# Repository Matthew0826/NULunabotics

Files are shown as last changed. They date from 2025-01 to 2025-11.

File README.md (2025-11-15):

Welcome to the NU Lunabotics Repository! This is the place for all IP for NU Lunabotics.

For Github to commit changes correctly ensure you run:
$ git config --global core.fileMode false

To run the repository in a docker container:
1. Open the project from the ROS folder (important so it can recognize our Dockerfile)
2. Ctrl + Shift + P
3. Open and Rebuild Container
4. $ ./launch_theia.sh to run the website + theia

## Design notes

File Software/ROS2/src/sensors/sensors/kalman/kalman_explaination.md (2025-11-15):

# Robot Location Tracking System

This code implements a location tracking system that uses distance measurements from fixed beacons and optional accelerometer data to figure out where a robot is. Let's break it down:

## What This Code Does

The system tracks a robot's position (x,y coordinates) by:
1. Taking distance measurements from three fixed beacons
2. Optionally using accelerometer data to improve accuracy
3. Applying statistical filtering to handle measurement errors
4. Estimating the most likely position based on all available data

## Core Components

### Main Classes

#### ExtendedKalmanFilter
This is the statistical heart of the system. It maintains an estimated state (position and velocity) and continuously refines it based on measurements.

```
Class ExtendedKalmanFilter:
    Initialize with:
        - Motion model (how we expect position to change over time)
        - Error models (how much we trust our predictions vs measurements)
        - Initial guess of position and velocity
        - Locations of fixed beacons
    
    Method predict():
        # Predict where robot should be now based on previous state
        Apply motion model to update state estimate
        Increase uncertainty to account for prediction errors
    
    Method update(distance_measurements, accel_measurements):
        # Validate incoming measurements first
        distances, accels = validate_measurements(...)
        
        # Calculate what measurements we'd expect to see if our current estimate is correct
        expected_distances = calculate_distances_from_current_estimate_to_beacons()
        
        # Compare actual to expected measurements (the difference is called "innovation")
        innovation = actual_measurements - expected_measurements
        
        # Calculate how much to trust these measurements
        adaptive_trust_factor = calculate_trust_based_on_measurement_quality()
        
        # Compute an optimal adjustment factor (balancing our prediction vs measurements)
        adjustment_factor = calculate_optimal_adjustment()
        
        # Update our position estimate using this balanced approach
        state = state + adjustment_factor * innovation
        
        # Update uncertainty estimates
        update_uncertainty_estimates()
        
        return innovation
        
    Method check_filter_health():
        # See if filter is working well or needs reset
        if position_uncertainty > THRESHOLD and consistent_large_errors:
            reset_uncertainty_to_reasonable_values()
            return True
        return False
```

### Helper Functions

```
Function validate_measurements(distance_measurements, accel_measurements):
    # Remove obviously wrong measurements
    Filter out distances < MIN_VALID_DISTANCE or > MAX_VALID_DISTANCE
    
    if accel_measurements provided:
        Filter out accelerations > MAX_VALID_ACCEL
        
    return cleaned_distances, cleaned_accels

Function adaptive_measurement_covariance(distances, accels):
    # Calculate how much to trust each measurement
    # Larger distances or accelerations get less trust
    
    for each distance:
        trust_factor = adjust_based_on_distance_magnitude()
    
    for each acceleration:
        trust_factor = adjust_based_on_acceleration_magnitude()
        
    return trust_factors
```

### Main Function

```
Function find_robot_location(distance_to_A, distance_to_B, distance_to_C, accel_x, accel_y):
    # Smooth accelerometer data with low-pass filter
    smoothed_accel = apply_low_pass_filter(accel_x, accel_y)
    
    # Update how much uncertainty to add in prediction step
    adjust_prediction_uncertainty(smoothed_accel)
    
    # Predict new position based on motion model
    ekf.predict()
    
    # Update estimate with new measurements
    innovation = ekf.update(distances, smoothed_accel)
    
    # Store history for diagnostics
    save_to_history(innovation, current_position, current_uncertainty)
    
    # Check if filter needs reset due to poor performance
    ekf.check_filter_health()
```

## How It Works (The Math Simplified)

1. **State Representation**: The system tracks four values in a vector: [x, vx, y, vy] where x,y are position and vx,vy are velocity

2. **Prediction Step**: At each time step (dt), the system predicts:
   ```
   new_x = x + vx*dt
   new_vx = vx
   new_y = y + vy*dt
   new_vy = vy
   ```

3. **Measurement Model**: It compares actual measurements with expected measurements:
   - Expected distance to each beacon = sqrt((x-beacon_x)² + (y-beacon_y)²)
   - Expected acceleration = 0 (assuming constant velocity)

4. **Update Step**: The system calculates:
   - Difference between actual and expected measurements
   - How much to trust each difference (based on distance size, acceleration size)
   - Optimal way to adjust current estimate based on new measurements
   - Updates position and velocity estimates accordingly

5. **Health Checks**: If uncertainty gets too high or measurements consistently disagree with predictions, the system resets its uncertainty estimates.

## Flow Summary

1. Initialize with a guess of robot position and reasonable uncertainty
2. For each new set of measurements:
   - Predict where robot should be now based on previous position and velocity
   - Compare beacon distances with expected distances
   - Calculate optimal adjustment to estimated position
   - Update position estimate and uncertainty values
   - Check if filter is working properly
   - Return best estimate of current position

This approach optimally balances the uncertainty in the motion model against the uncertainty in the sensor measurements, giving more weight to whichever is more reliable at any given moment.

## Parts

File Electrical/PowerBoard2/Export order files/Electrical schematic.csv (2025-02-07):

Reference | Value | Datasheet | Footprint | Qty | DNP
C1,C2 | 20SVPF120M | 20SVPF120M | PCAP_SVP_C6_PAN | 2
C3 | 25SVPF47M | 25SVPF47M | PCAP_SVP_C6_PAN | 1
C10 | 0.1uF | ~ | Capacitor_SMD:C_0805_2012Metric_Pad1.18x1.45mm_HandSolder | 1
C11 | 1nF | ~ | Capacitor_SMD:C_0805_2012Metric_Pad1.18x1.45mm_HandSolder | 1
J1 | S4B-XH-SM4-TB | S4B-XH-SM4-TB | CONN4_S4B-XH_JST | 1
J2,J3,J5 | XT60PW-M |  | Connector_AMASS:AMASS_XT60IPW-M_1x03_P7.20mm_Horizontal | 3
J4 | 2171750001 | 2171750001 | 2171750001_MOL | 1
R1 | ERJ-6ENF1071V | ERJ-6ENF1071V | RC0805N_PAN | 1
R2 | ERJ-6ENF5621V | ERJ-6ENF5621V | RC0805N_PAN | 1
R3,R4 | 5.1k | ~ | Resistor_SMD:R_0805_2012Metric_Pad1.20x1.40mm_HandSolder | 2
R5 | 1M | ~ | Resistor_SMD:R_0805_2012Metric_Pad1.20x1.40mm_HandSolder | 1
R6 | 0.333M | ~ | Resistor_SMD:R_0805_2012Metric_Pad1.20x1.40mm_HandSolder | 1
U1 | LMZ22005TZ/NOPB | LMZ22005TZ/NOPB | TZA07A | 1
U2 | ACS715LLCTR-30A-T | ACS715LLCTR-30A-T | SOIC-8_ALM | 1
U3 | TLV2370IDBVR |  | TLV2370IDBVR:SOT95P280X145-6N | 1
U4 | TMUX1204DGSR | TMUX1204DGSR | DGS0010A-IPC_A | 1

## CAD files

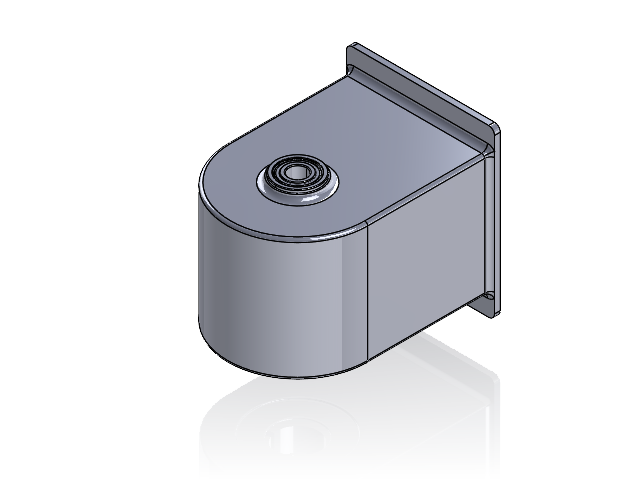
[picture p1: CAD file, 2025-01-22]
2XX-XXXX (Mechanical)/21X-XXXX (Mobility)/211-XXXX (Drivetrain)/211-00XX (Swerve System)/211-009X (Sub-Assemblies)/211-0092 (Differential Gearbox Assembly).SLDASM
211-0021 (Gearbox Casing)
211-0022 (28 Tooth Bevel Gear).step x 2
1301-0016-0014.STEP
2800-0004-0010_90128A207.STEP
1311-0016-1006.STEP
2800-0004-0014_90128A207.STEP x 2
211-0001 (6mm ID Flanged Bearing).step x 2
211-0025 (Central Spacer)

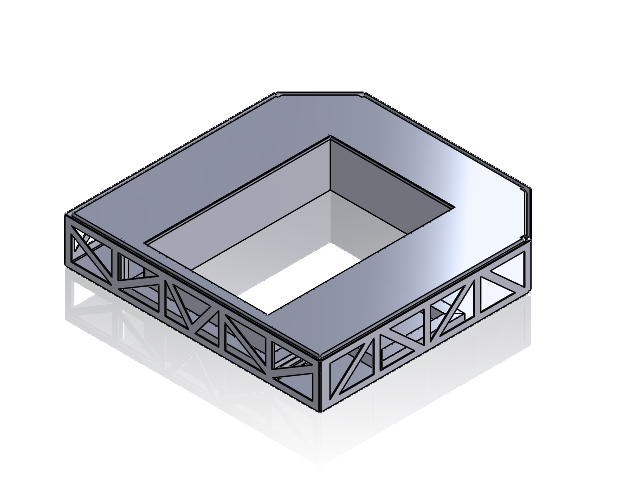
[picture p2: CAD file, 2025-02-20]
Mechanical/Chassis/Sheet Metal Chassis/Chassis2_Assy.SLDASM
Chassis_Bottom-Shell
Chassis Frame
Chassis_Rib
Chassis_Rib2
296x110_Panel x 2
450x110_Panel x 2
Chassis_Top-Shell

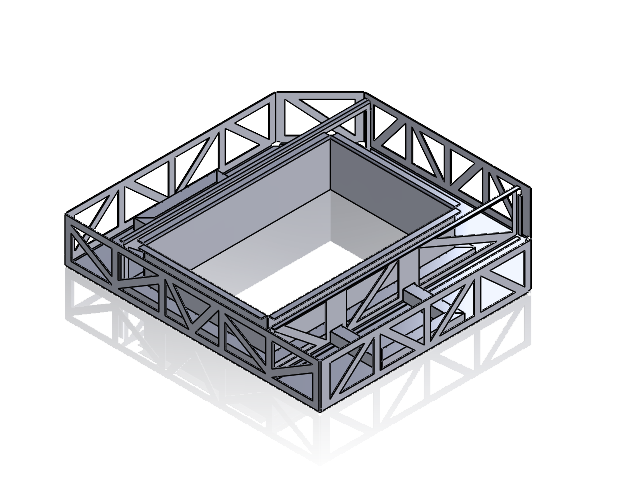
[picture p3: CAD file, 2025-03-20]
Mechanical/Lunabotics2025_Chassis_Design/CAD_Lunbotics 2025/Chassis2_Assy.SLDASM
Chassis_Bottom-Shell
Chassis Frame
Chassis_Rib
Chassis_Rib2
296x110_Panel x 2
450x110_Panel x 2

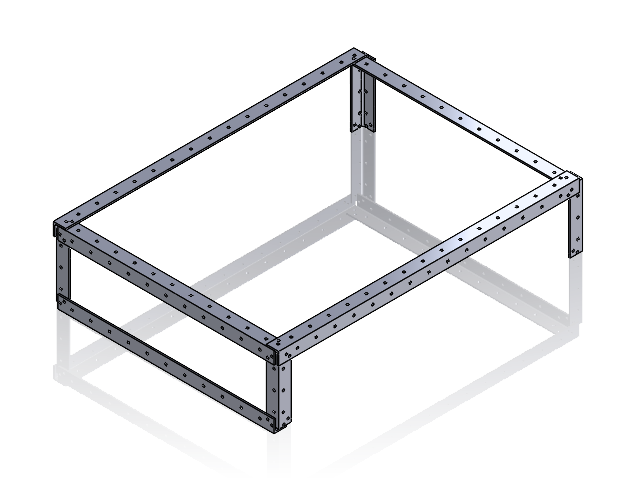
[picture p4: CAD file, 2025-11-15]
Mechanical/Lunabotics2025_Chassis_Design/Chassis_3/L-Bar Frame.SLDASM
L-Bar_1x1_8th_inch_558.8mm x 3
L-Bar_1x1_8th_inch x 2
L-Bar_1x1_8th_4inch x 4

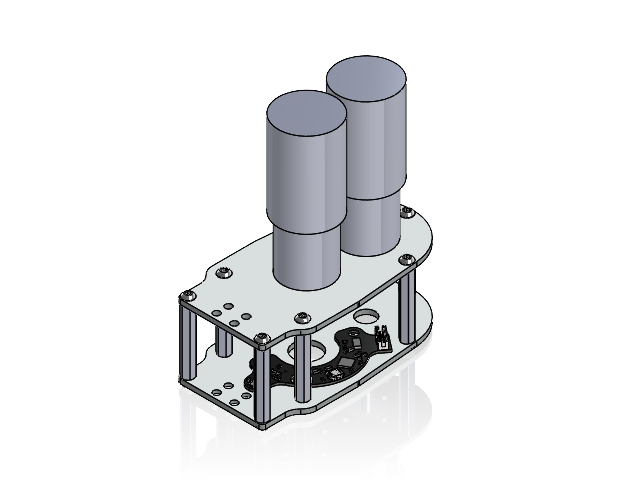
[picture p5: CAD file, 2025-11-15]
Mechanical/Experimental/Swerve Modules/Chassis Structure/Fixed Components/Gearbox Casing/Gearbox Casing Assembly.SLDASM
Top Interface Panel
Motor Mounting Plate
Lamprey
Motor x 2
43mm Hex Standoff.step x 7
M4 Button Head 12mm x 14

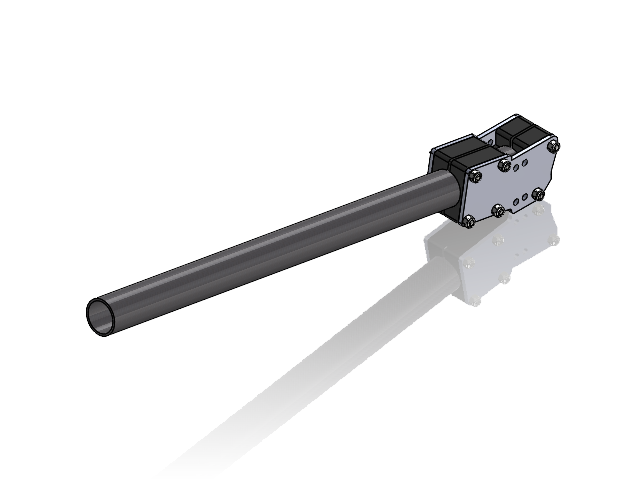
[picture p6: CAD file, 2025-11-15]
Mechanical/Experimental/Swerve Modules/Chassis Structure/Fixed Components/Tube Mount/Tube Mount Assembly.SLDASM
Tube
Tube Clamp Left
Tube Clamp Right
Tube Clamp Plate x 2
M4 40mm x 6
M4 Lock Nut x 6

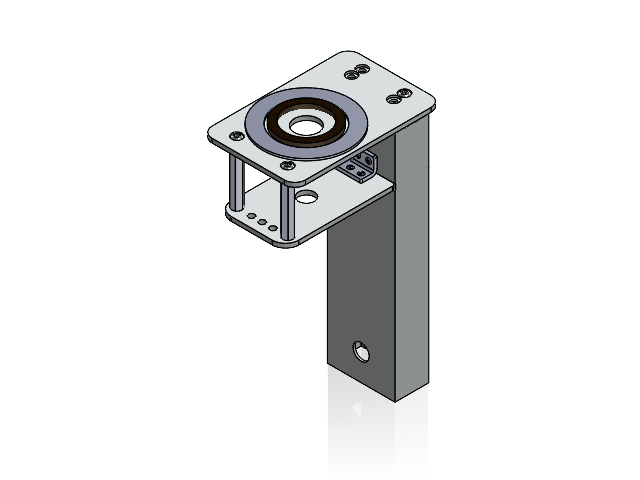
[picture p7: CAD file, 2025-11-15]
Mechanical/Experimental/Swerve Modules/Wheel Structure/Fixed Components/Differential Gearbox Case.SLDASM
Bottom Interface Plate
43mm Hex Standoff.step x 2
M4 Button Head 12mm x 2
Modified GoBilda L-Bracket x 2
Wheel Tube
Wheel Cover Plate
Lamprey Magnet Ring.step
GoBilda L-Bracket.step x 2
Part9^Thrust Bearing
5mm M4 Bolt

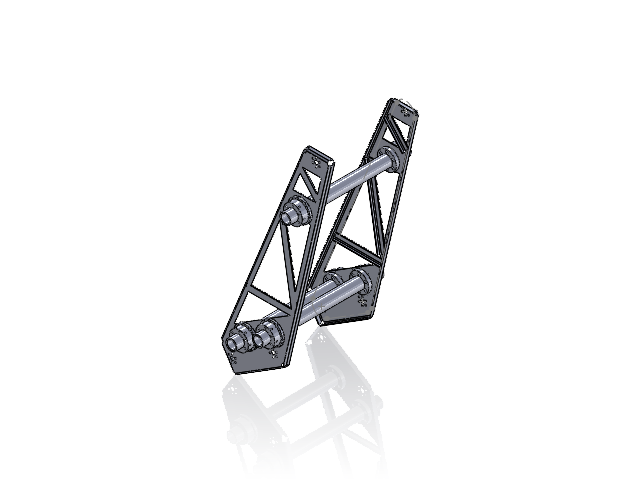
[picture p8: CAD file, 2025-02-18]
Mechanical/Lunabotics2025_Chassis_Design/Conveyer/Conveyer_Assy.SLDASM
Rib_1 x 2
Rib_2 x 2
Rib_3 x 2
Side_Frame
Side_Frame_2
300MM_PVC x 3
PVC_Attachment1 x 6
PVC_Attachment2 x 6

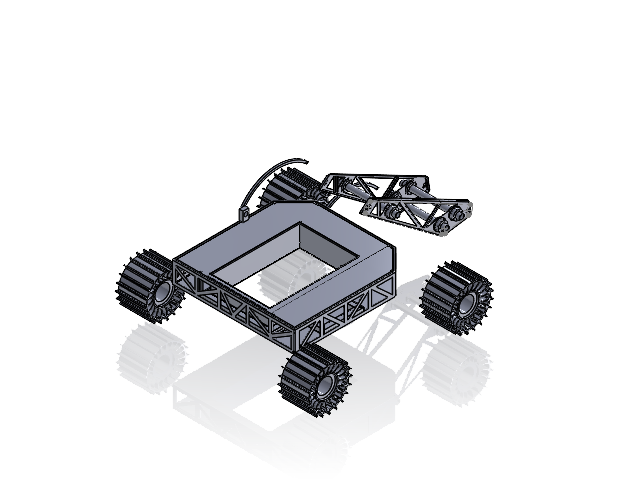
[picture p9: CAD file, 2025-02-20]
Mechanical/Chassis/Maharshi Blocking/Luna_Assy.SLDASM
Chassis_Bottom-Shell
Chassis Frame
Chassis_Rib
Chassis_Rib2
296x110_Panel x 2
450x110_Panel x 2
Chassis_Top-Shell
Rib_1 x 2
Rib_2 x 2
Rib_3 x 2
Side_Frame
Side_Frame_2
300MM_PVC x 3
PVC_Attachment1 x 6
PVC_Attachment2 x 6
Dummy_Wheel_226mm x 4
Dummy_Hinge x 2
Dummy_Arm-1
Dummy_Arm-2

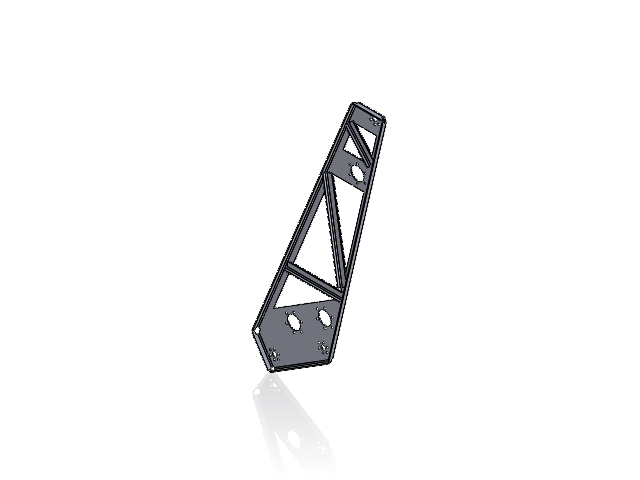
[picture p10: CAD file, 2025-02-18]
Mechanical/Lunabotics2025_Chassis_Design/Conveyer/Side_Frame_1_assy.SLDASM
Rib_1
Rib_2
Rib_3
Side_Frame

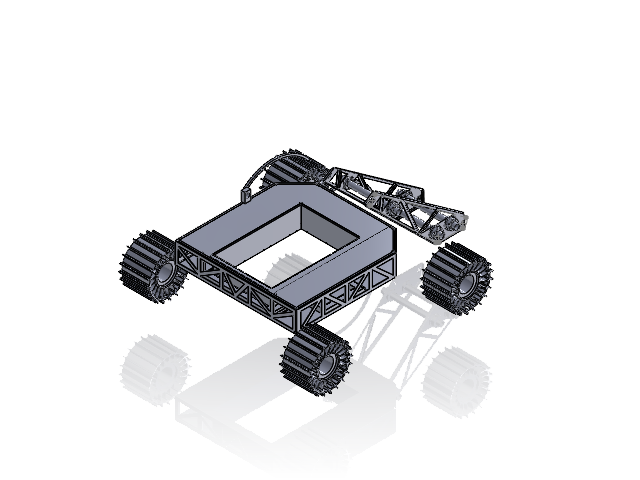
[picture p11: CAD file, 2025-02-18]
Mechanical/Lunabotics2025_Chassis_Design/Luna_Assy.SLDASM
Chassis_Bottom-Shell
Chassis Frame
Chassis_Rib
Chassis_Rib2
296x110_Panel x 2
450x110_Panel x 2
Chassis_Top-Shell
Rib_1 x 2
Rib_2 x 2
Rib_3 x 2
Side_Frame
Side_Frame_2
300MM_PVC x 3
PVC_Attachment1 x 6
PVC_Attachment2 x 6
Dummy_Wheel_226mm x 4
Dummy_Hinge x 2
Dummy_Arm-1
Dummy_Arm-2

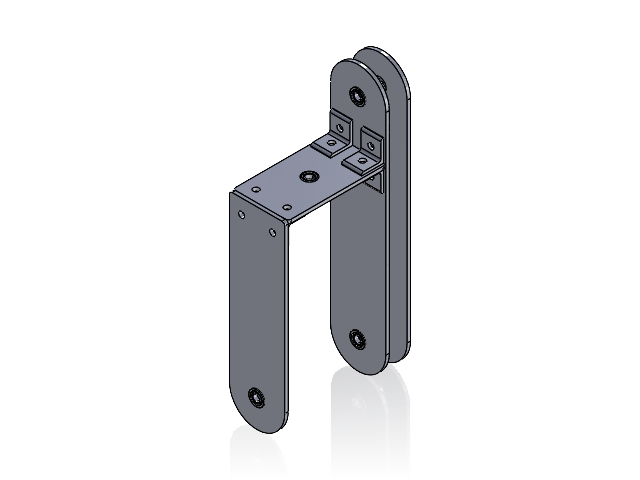
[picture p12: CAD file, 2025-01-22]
Mechanical/Experimental/Swerve Modules/Wheel Mount Assembly.SLDASM
211-0002 (Master Sketch v2)
211-0010 (Belt Protection Panel)
211-0016 (Outer Belt Protection Panel)
211-0018 (Wheel Top Plate)
211-0015 (Corner Bracket) x 6
211-0017 (Wheel Support Plate)
211-0012 (6mm ID 12mm OD Flanged Bearing).step x 6

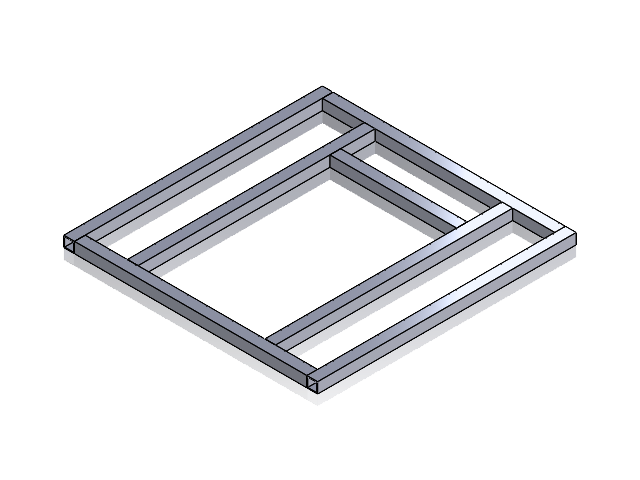
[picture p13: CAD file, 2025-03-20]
Mechanical/Lunabotics2025_Chassis_Design/Chassis_2/Chassis_2_Frame_Assy.SLDASM
1x1inch_612mmBeam x 2
1x1inch_550mmBeam x 2
1x1inch_561.2mmBeam x 2
1x1inch_300mmBeam

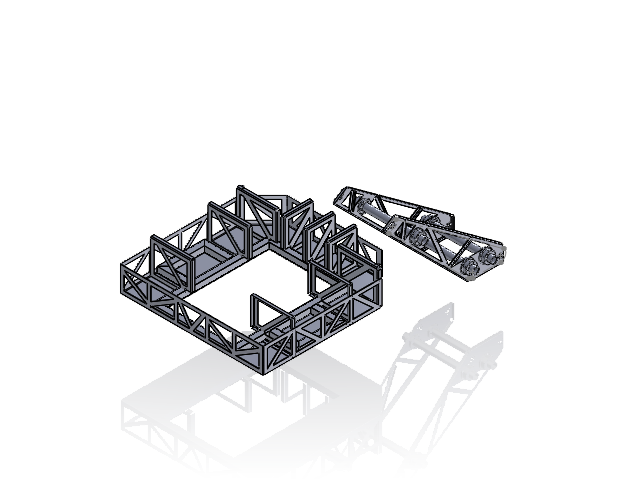
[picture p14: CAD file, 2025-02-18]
Mechanical/Lunabotics2025_Chassis_Design/CAD_Lunbotics 2025/Chassis_Assy.SLDASM
Chassis_Bottom-Shell
Chassis Frame
Front_L-Bracket x 3
Front_Left-Corner_L-Bracket
Front_Right-Corner_L-Bracket
Side_L-Bracket x 4
Rib_1 x 2
Rib_2 x 2
Rib_3 x 2
Side_Frame
Side_Frame_2
300MM_PVC x 3
PVC_Attachment1 x 6
PVC_Attachment2 x 6

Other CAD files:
Mechanical/Excavation/Conveyer/Conveyer_Assy.SLDASM
Mechanical/Experimental/Swerve Modules/Wheel Structure/Fixed Components/Thrust Bearing.SLDASM
Mechanical/Lunabotics2025_Chassis_Design/Chassis_2/Chassis_2_Assy.SLDASM
Electrical/SparkMiniMount.SLDPRT
Mechanical/4BarGBInnerLg.STL
Mechanical/4BarGBInnerLgr.STL
Mechanical/4BarGBOuter.STL
Mechanical/4BarGearboxLg.STL
Mechanical/4BarGearboxSmall.SLDPRT
Mechanical/4BarGearboxSmall.STL
Mechanical/;;.dxf
Mechanical/Big Boi Cut.DWG
Mechanical/Big Boi Cut_imported_DWG.dxf
Mechanical/Blocking.SLDPRT
Mechanical/Blockingv2.DWG
Mechanical/Blockingv2.SLDPRT
Mechanical/Chassis/Chassis v2/Chassis_2_Assy.SLDASM
Mechanical/Chassis/Chassis v3/12x6inch_side_frame.SLDPRT
Mechanical/Chassis/Chassis v3/Bottom_Plate.SLDPRT
Mechanical/Chassis/Chassis v3/Chassis_3_assy.SLDASM
Mechanical/Chassis/Chassis v3/L-Bar_1x1_8th_4inch.SLDPRT
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

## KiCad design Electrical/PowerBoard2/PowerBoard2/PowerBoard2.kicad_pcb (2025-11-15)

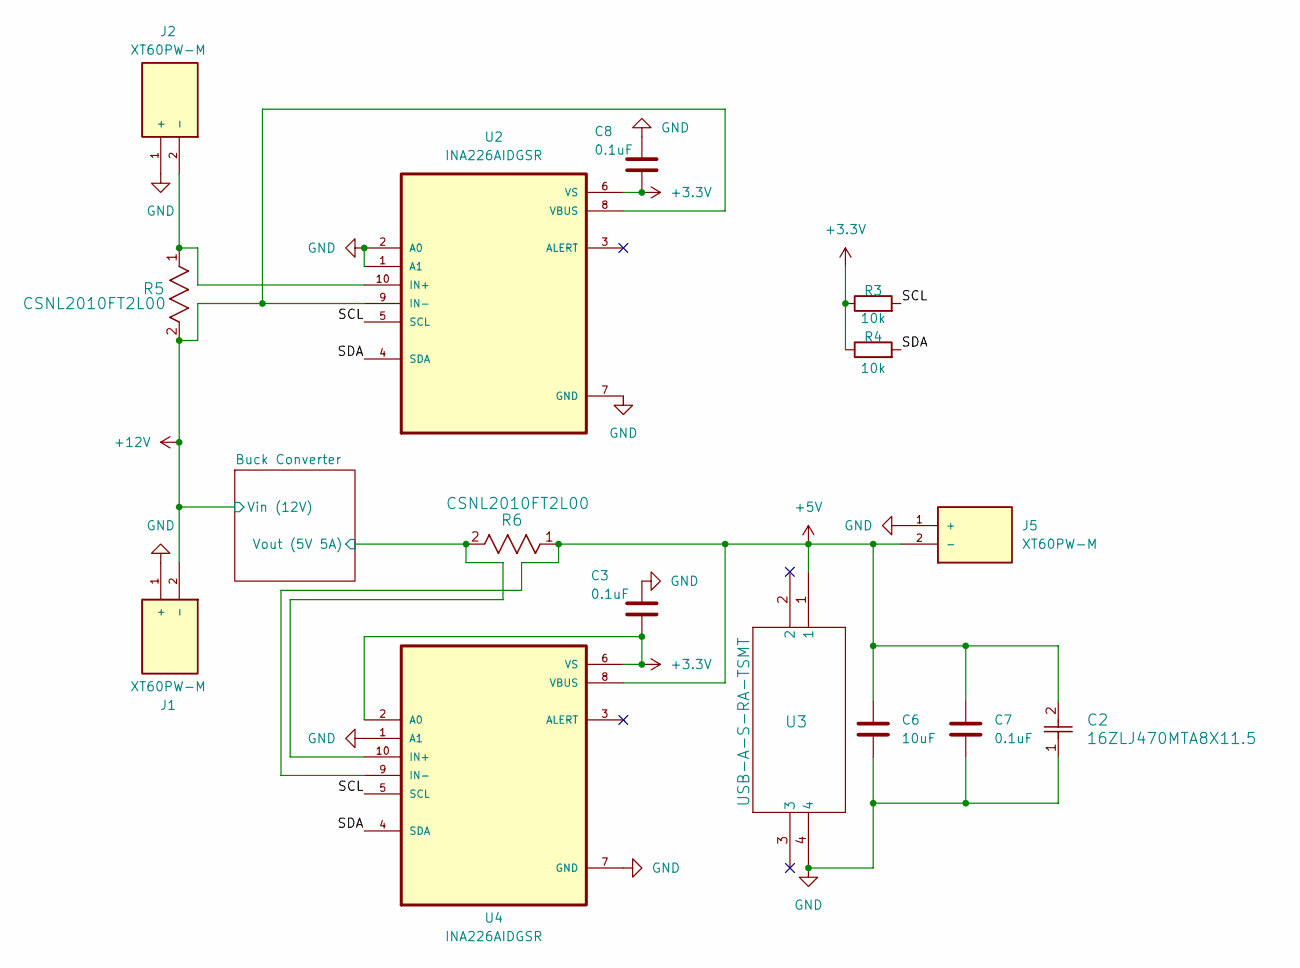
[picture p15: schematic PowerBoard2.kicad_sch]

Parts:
C2: 16ZLJ470MTA8X11.5; CAP_YX_8X11P5_RUB
C3, C7, C8: 0.1uF; C_0805_2012Metric_Pad1.18x1.45mm_HandSolder
C6: 10uF; C_0805_2012Metric_Pad1.18x1.45mm_HandSolder
J1, J2, J5: XT60PW-M; AMASS_XT60IPW-M_1x03_P7.20mm_Horizontal; PARTREV V1.2
R3, R4: 10k; R_0805_2012Metric_Pad1.20x1.40mm_HandSolder
R5, R6: CSNL2010FT2L00; STA_CSNL2010&lessthan_=3_STP
U2, U4: INA226AIDGSR
U3: USB-A-S-RA-TSMT; USB-A-S-RA-TSMT_ADM

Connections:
+3.3V: C3.1, C8.1, R3.1, R4.1, U2.6 (VS), U4.2 (A0), U4.6 (VS); also elsewhere on the board
+5V: C2.2, C6.1, C7.1, J5.2 (-), R6.1, U3.1, U4.8 (VBUS), U4.9 (IN-); also elsewhere on the board
+12V: J1.2 (-), R5.2, U2.8 (VBUS), U2.9 (IN-); also elsewhere on the board
/Buck Converter/Vout (5V 5A): R6.2, U4.10 (IN+); also elsewhere on the board
/SCL: R3.2, U2.5 (SCL), U4.5 (SCL); also elsewhere on the board
/SDA: R4.2, U2.4 (SDA), U4.4 (SDA); also elsewhere on the board
GND: C2.1, C3.2, C6.2, C7.2, C8.2, J1.1 (+), J2.1 (+), J5.1 (+), U2.1 (A1), U2.2 (A0), U2.7 (GND), U3.4, U4.1 (A1), U4.7 (GND); also elsewhere on the board
unnamed: J2.2 (-), R5.1, U2.10 (IN+)

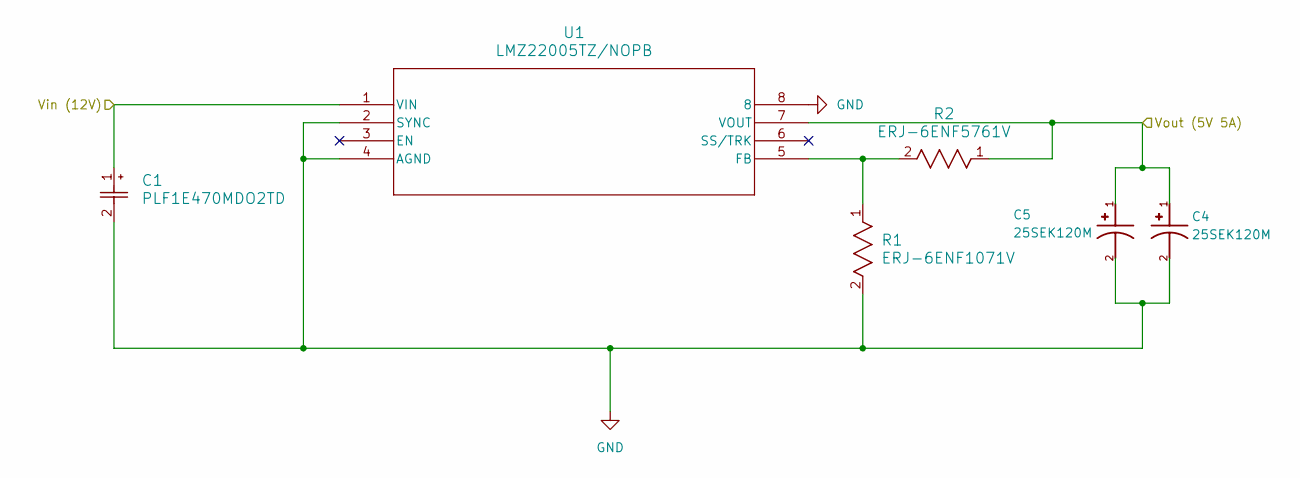
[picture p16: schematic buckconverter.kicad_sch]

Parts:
C1: PLF1E470MDO2TD
C4, C5: 25SEK120M; PARTREV 30-Oct-17
R1: ERJ-6ENF1071V; RC0805N_PAN
R2: ERJ-6ENF5761V; RC0805N_PAN
U1: LMZ22005TZ/NOPB; TZA07A

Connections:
+12V: C1.1, U1.1 (VIN); also elsewhere on the board
/Buck Converter/Vout (5V 5A): C4.1, C5.1, R2.1, U1.7 (VOUT); also elsewhere on the board
GND: C1.2, C4.2, C5.2, R1.2, U1.2 (SYNC), U1.4 (AGND), U1.8; also elsewhere on the board
unnamed: R1.1, R2.2, U1.5 (FB)

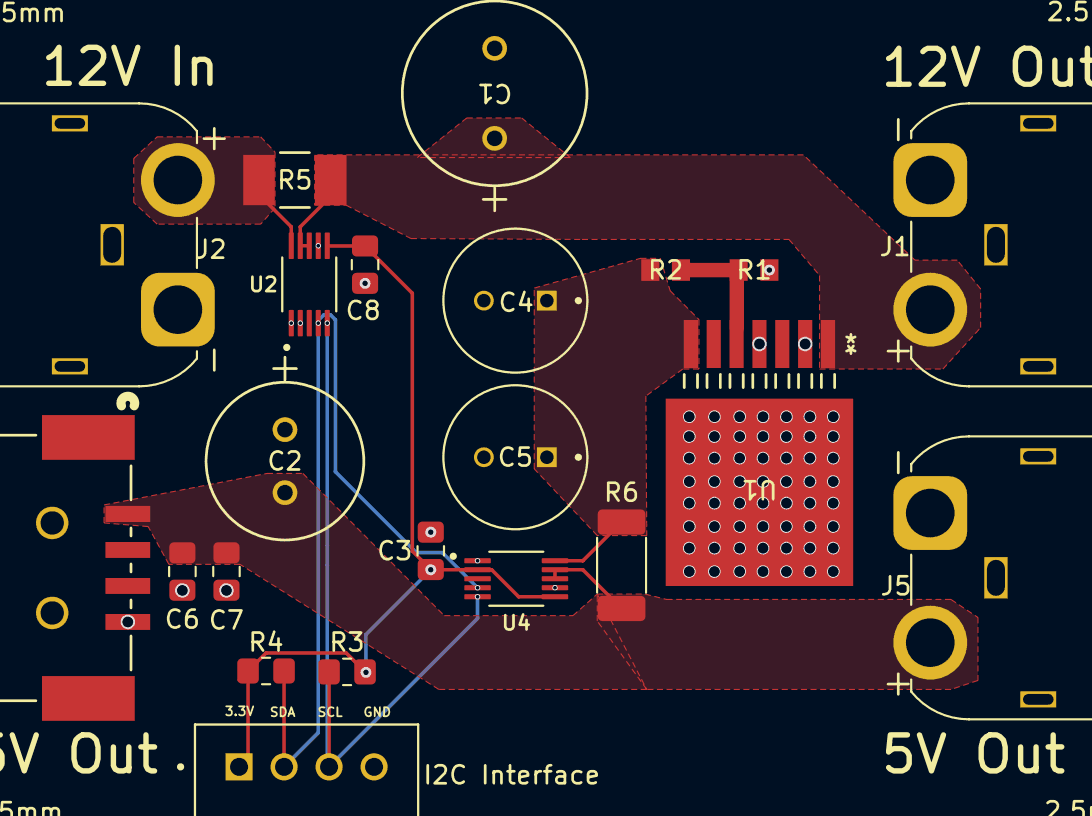
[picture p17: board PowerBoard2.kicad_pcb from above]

Board: 2 copper layers, 26 parts (0 on the bottom side), 9 nets.

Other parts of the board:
2.5mm, 2.5mm#2, 2.5mm#3, 2.5mm#4: MountingHole_2.5mm
5V Out: USB-A-S-RA-TSMT; USB-A-S-RA-TSMT_ADM
I2C Interface: B4B-XH-A_LF__SN_; JST_B4B-XH-A_LF__SN_

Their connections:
+3.3V: I2C Interface.1; also elsewhere on the board
+5V: 5V Out.1; also elsewhere on the board
/SCL: I2C Interface.3; also elsewhere on the board
/SDA: I2C Interface.2; also elsewhere on the board
GND: 5V Out.4, I2C Interface.4; also elsewhere on the board

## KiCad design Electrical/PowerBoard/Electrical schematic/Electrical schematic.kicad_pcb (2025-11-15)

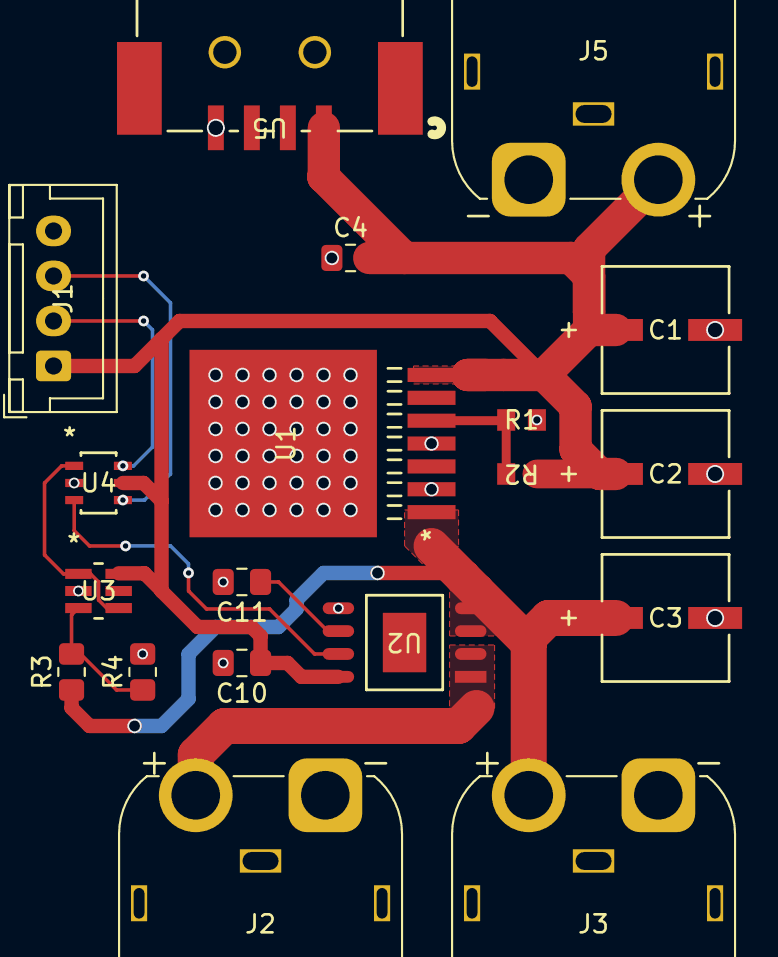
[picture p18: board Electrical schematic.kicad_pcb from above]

Board: 2 copper layers, 19 parts (0 on the bottom side), 11 nets.

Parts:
C1, C2: 20SVPF120M; PCAP_SVP_C6_PAN
C3: 25SVPF47M; PCAP_SVP_C6_PAN
C4: 330uF; C_0805_2012Metric_Pad1.18x1.45mm_HandSolder
C10: 0.1uF; C_0805_2012Metric_Pad1.18x1.45mm_HandSolder
C11: 1nF; C_0805_2012Metric_Pad1.18x1.45mm_HandSolder
J1: S4B-XH-SM4-TB; JST_XH_B4B-XH-A_1x04_P2.50mm_Vertical
J2, J3, J5: XT60PW-M; AMASS_XT60IPW-M_1x03_P7.20mm_Horizontal
R1: ERJ-6ENF1071V; RC0805N_PAN
R2: ERJ-6ENF5761V; RC0805N_PAN
R3: 1M; R_0805_2012Metric_Pad1.20x1.40mm_HandSolder
R4: 0.333M; R_0805_2012Metric_Pad1.20x1.40mm_HandSolder
U1: LMZ22005TZ/NOPB; TZA07A
U2: ACS715LLCTR-30A-T; SOIC-8_ALM
U3: TLV2370IDBVR; DBV6
U4: 74LVC1G157GV_125; TSOP6_SOT457_NEX
U5: USB-A-S-RA-TSMT; USB-A-S-RA-TSMT_ADM

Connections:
/Buck Converter/Vin (12V): C3.1, J3.2 (-), R3.1, U1.1 (VIN), U2.3 (IP-), U2.4 (IP-)
/Buck Converter/Vout (5V 5A): C1.1, C2.1, C4.2, C10.1, J1.1, J5.2 (-), R2.1, U1.7 (VOUT), U2.8 (VCC), U3.6 (VDD), U4.5 (VCC), U5.1
/Current Sensor/CURRENT IN: J2.2 (-), U2.1 (IP+), U2.2 (IP+)
/Current Sensor/VOLTAGE OUT (of reading): U2.7 (VIOUT), U4.3 (I0)
GND: C1.2, C2.2, C3.2, C4.1, C10.2, C11.2, J1.4, J2.1 (+), J3.1 (+), J5.1 (+), R1.2, R4.2, U1.2 (SYNC), U1.4 (AGND), U1.8, U2.5 (GND), U3.2 (GND), U4.2 (GND), U5.4
unnamed: R1.1, R2.2, U1.5 (FB)
unnamed: C11.1, U2.6 (FILTER)
unnamed: R3.2, R4.1, U3.3 (IN+)
unnamed: U3.1 (OUT), U3.4 (IN-), U4.1 (I1)
unnamed: J1.2, U4.6 (S)
unnamed: J1.3, U4.4 (Y)

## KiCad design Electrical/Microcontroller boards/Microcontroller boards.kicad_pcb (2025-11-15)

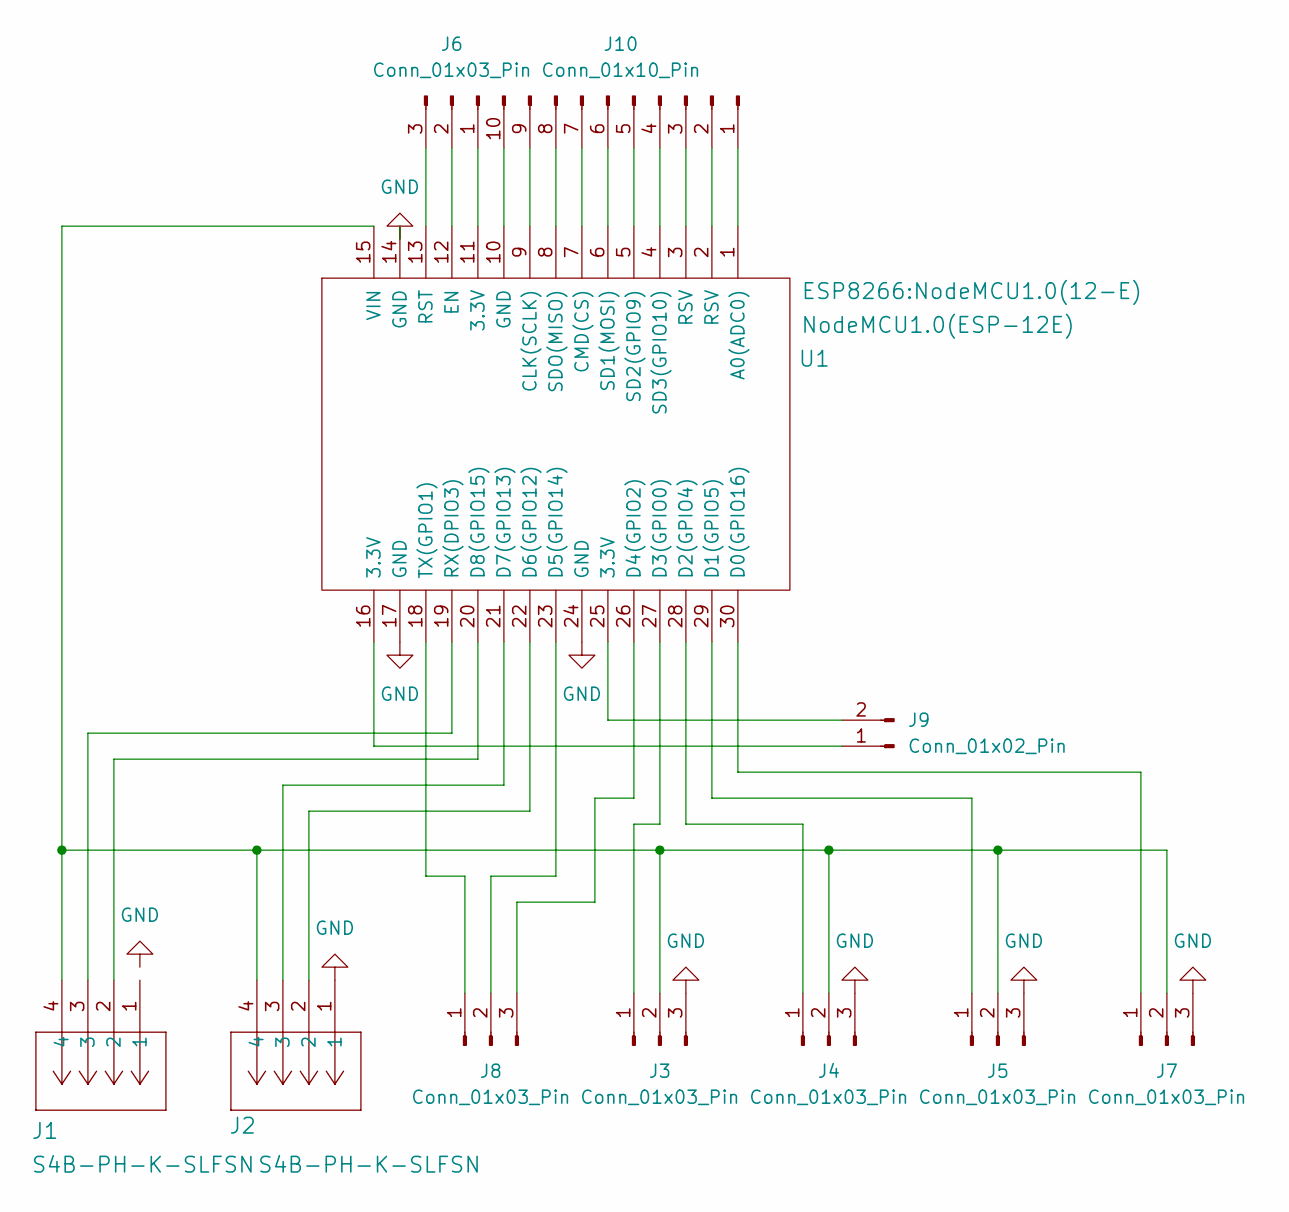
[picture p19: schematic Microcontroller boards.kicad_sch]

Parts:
J1, J2: S4B-PH-K-SLFSN; CONN_S4B-PH-K-S_JST
J3, J4, J5, J6, J7, J8: Conn_01x03_Pin; Wuerth_WR-WTB_64800311622_1x03_P1.50mm_Vertical
J9: Conn_01x02_Pin; Wuerth_WR-WTB_64800311622_1x02_P1.50mm_Vertical
J10: Conn_01x10_Pin; Wuerth_WR-WTB_64801011622_1x10_P1.50mm_Vertical
U1: NodeMCU1.0(ESP-12E); NodeMCU1.0(12-E)

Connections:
GND: J2.1, J3.3, J4.3, J5.3, J7.3, U1.14 (GND), U1.17 (GND), U1.24 (GND)
unnamed: J3.1, U1.27 (D3(GPIO0))
unnamed: J1.4, J2.4, J3.2, J4.2, J5.2, J7.2, U1.15 (VIN)
unnamed: J4.1, U1.28 (D2(GPIO4))
unnamed: J5.1, U1.29 (D1(GPIO5))
unnamed: J6.1, U1.11 (3.3V)
unnamed: J6.2, U1.12 (EN)
unnamed: J6.3, U1.13 (RST)
unnamed: J7.1, U1.30 (D0(GPIO16))
unnamed: J8.1, U1.18 (TX(GPIO1))
unnamed: J8.2, U1.23 (D5(GPIO14))
unnamed: J8.3, U1.26 (D4(GPIO2))
unnamed: J9.1, U1.16 (3.3V)
unnamed: J9.2, U1.25 (3.3V)
unnamed: J10.1, U1.1 (A0(ADC0))
unnamed: J10.2, U1.2 (RSV)
unnamed: J10.3, U1.3 (RSV)
unnamed: J10.4, U1.4 (SD3(GPIO10))
unnamed: J10.5, U1.5 (SD2(GPIO9))
unnamed: J10.6, U1.6 (SD1(MOSI))
unnamed: J10.7, U1.7 (CMD(CS))
unnamed: J10.8, U1.8 (SDO(MISO))
unnamed: J10.9, U1.9 (CLK(SCLK))
unnamed: J10.10, U1.10 (GND)
unnamed: J2.2, U1.22 (D6(GPIO12))
unnamed: J2.3, U1.21 (D7(GPIO13))
unnamed: J1.2, U1.20 (D8(GPIO15))
unnamed: J1.3, U1.19 (RX(DPIO3))

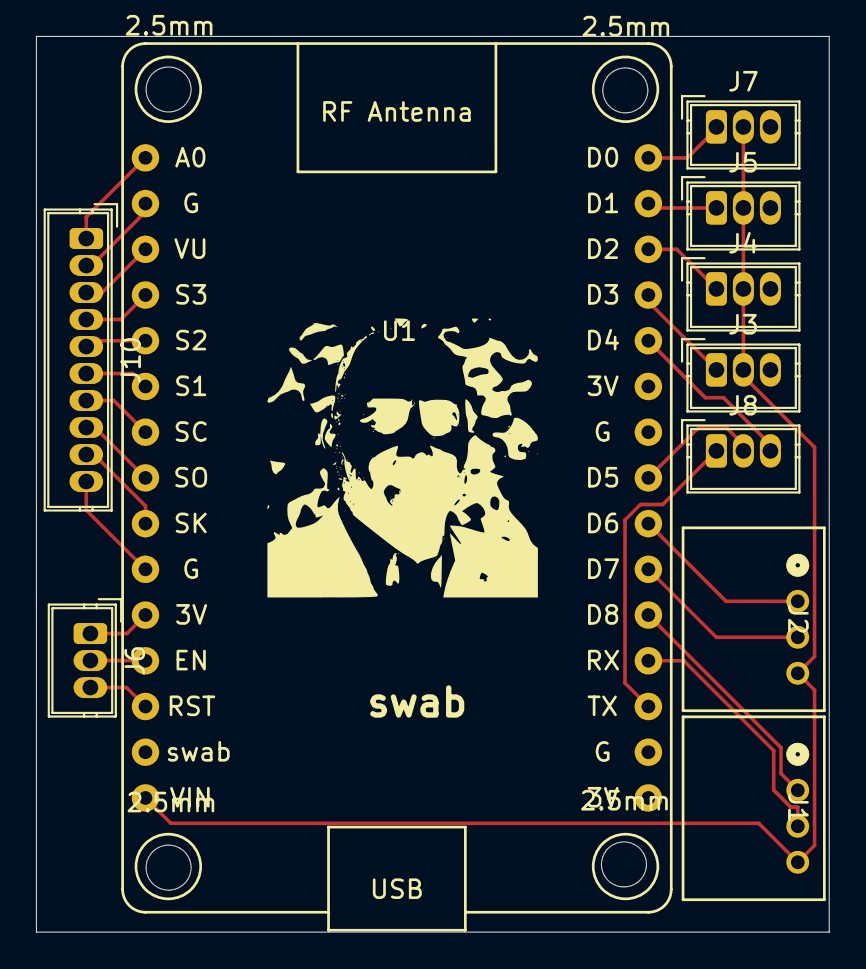
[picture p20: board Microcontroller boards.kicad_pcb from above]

Board: 2 copper layers, 44.0 x 49.8 mm, 15 parts (0 on the bottom side), 26 nets.

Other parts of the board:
2.5mm, 2.5mm#2, 2.5mm#3, 2.5mm#4: MountingHole_2.5mm
swab: LOGO

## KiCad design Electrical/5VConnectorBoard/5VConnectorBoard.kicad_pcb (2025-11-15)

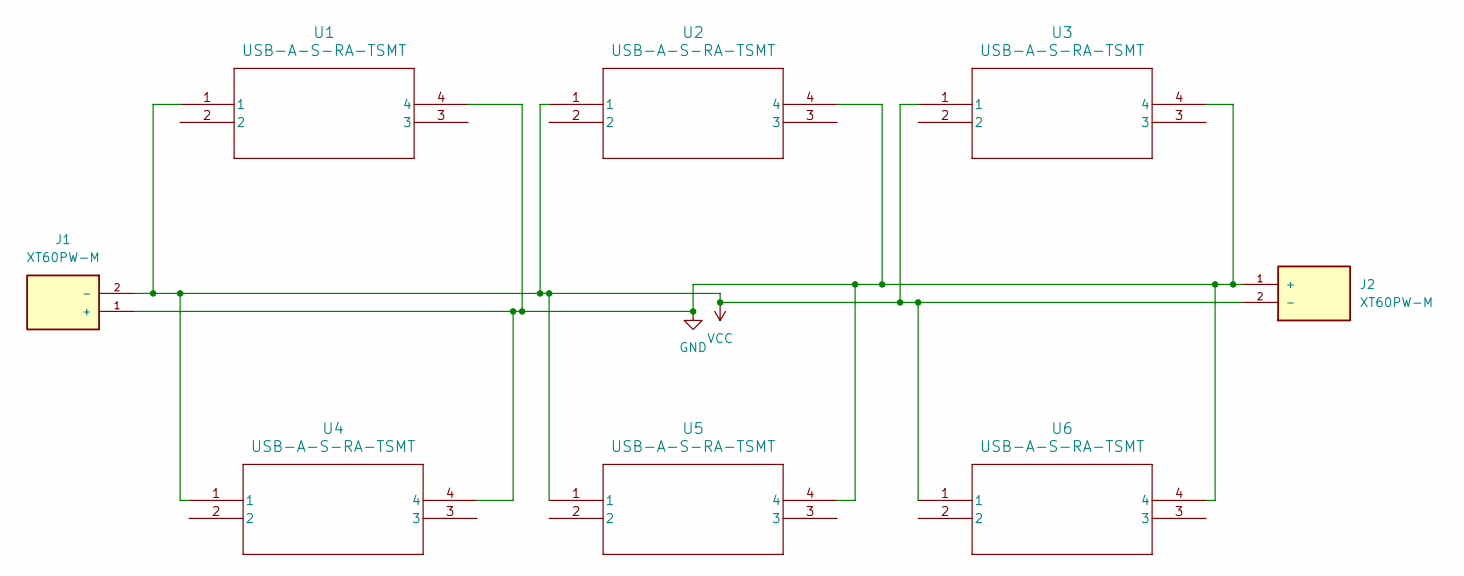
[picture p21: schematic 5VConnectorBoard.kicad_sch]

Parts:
J1, J2: XT60PW-M; AMASS_XT60PW-M_1x02_P7.20mm_Horizontal; PARTREV V1.2
U1, U2, U3, U4, U5, U6: USB-A-S-RA-TSMT; USB-A-S-RA-TSMT_ADM

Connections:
GND: J1.1 (+), J2.1 (+), U1.4, U2.4, U3.4, U4.4, U5.4, U6.4
VCC: J1.2 (-), J2.2 (-), U1.1, U2.1, U3.1, U4.1, U5.1, U6.1

Board: 2 copper layers, 8 parts (0 on the bottom side), 2 nets, no tracks yet.

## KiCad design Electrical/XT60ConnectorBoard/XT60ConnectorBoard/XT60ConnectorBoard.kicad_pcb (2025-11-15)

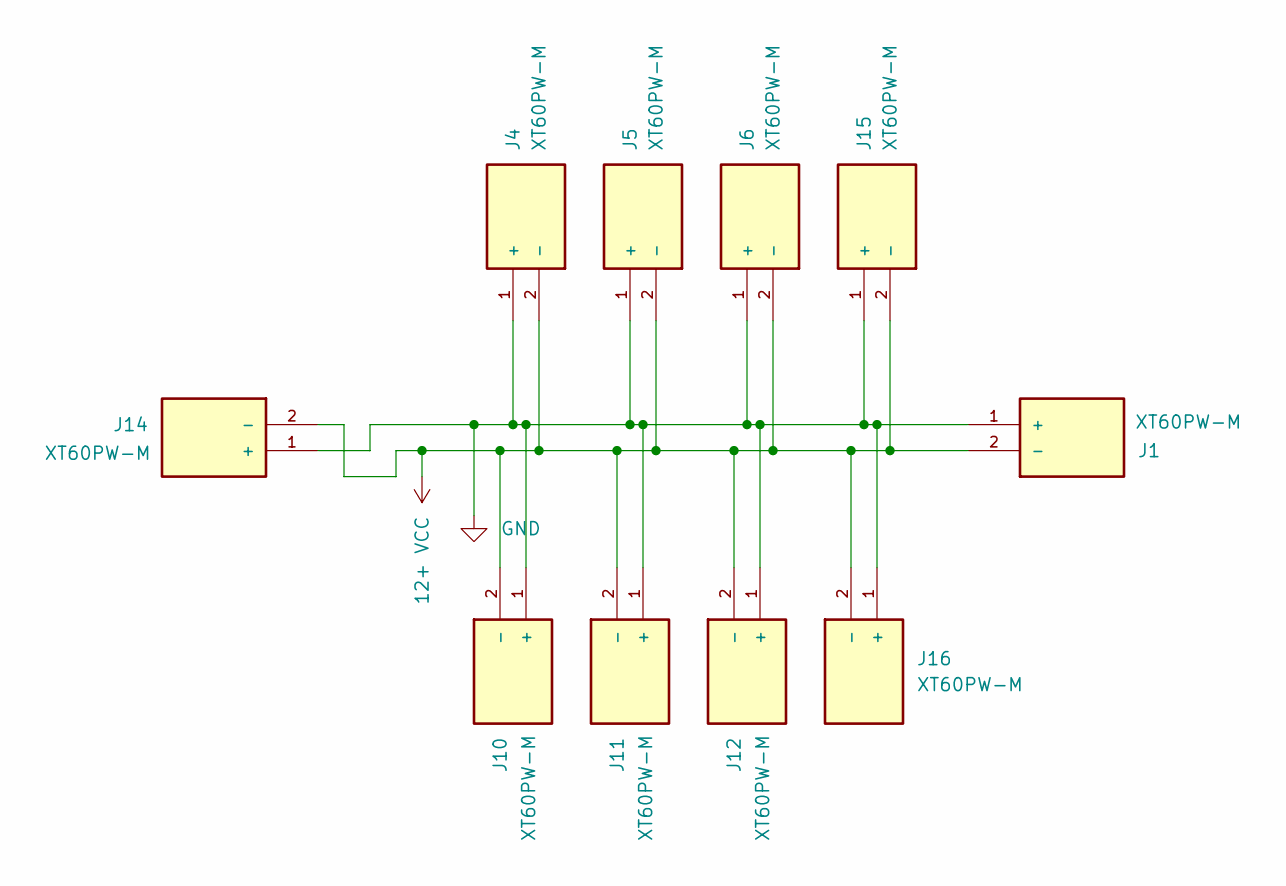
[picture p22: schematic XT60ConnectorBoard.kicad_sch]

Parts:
J1, J4, J5, J6, J10, J11, J12, J14, J15, J16: XT60PW-M; AMASS_XT60PW-M_1x02_P7.20mm_Horizontal; PARTREV V1.2

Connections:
12+ VCC: J1.2 (-), J4.2 (-), J5.2 (-), J6.2 (-), J10.2 (-), J11.2 (-), J12.2 (-), J14.2 (-), J15.2 (-), J16.2 (-)
GND: J1.1 (+), J4.1 (+), J5.1 (+), J6.1 (+), J10.1 (+), J11.1 (+), J12.1 (+), J14.1 (+), J15.1 (+), J16.1 (+)

Board: 2 copper layers, 10 parts (0 on the bottom side), 2 nets, no tracks yet.

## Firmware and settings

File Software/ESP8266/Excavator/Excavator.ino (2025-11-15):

#include <Servo.h>
#include <TheiaSerial.h>

#define EXCAVATOR_ID 5
#define EXCAVATOR_PERCENT_ID 6
#define EXCAVATOR_DISTANCE_ID 7

// Using the SPARKmini Motor Controller
#define FORWARD_PULSE_WIDTH 2500.0 // in microseconds
#define REVERSE_PULSE_WIDTH 500.0 // in microseconds

#define DISTANCE_SENSOR_PIN A4
#define ACTUATOR_POTENTIOMETER_PIN A3
#define EXCAVATOR_POTENTIOMETER_PIN A5
#define LIMIT_SWITCH_PIN 7

#define MAX_VOLTS 5.0
#define BOARD_MAX_ANALOG_VALUE 1023.0

#define ACTUATOR_LIMIT_TOLERANCE 0.02

#define MOTOR_COUNT 3
byte motorPins[MOTOR_COUNT] = {6, 5, 9};
Servo motors[MOTOR_COUNT];

int loopCount = 0;
float actuatorPercent = 0.0;
float excavatorPercent = 0.0;
bool isLimitSwitchTriggered = false;

typedef struct {
    float excavatorLifterSpeed;
    float conveyorSpeed;
    float actuatorSpeed;
} ExcavatorState;

typedef struct {
  float excavatorLifterPercent;
  float actuatorPercent;
} PotentiometerPercents;

typedef struct {
    float distanceSensor;
} DistanceSensor;

void nothingCallback(const PotentiometerPercents& percent) {
    // nothing
}

void nothingCallback2(const DistanceSensor& percent) {
    // nothing
}

void setup() {
  TheiaSerial::begin();
  TheiaSerial::addId<ExcavatorState>(EXCAVATOR_ID, onExcavatorState);
  TheiaSerial::addId<PotentiometerPercents>(EXCAVATOR_PERCENT_ID, nothingCallback);
  TheiaSerial::addId<DistanceSensor>(EXCAVATOR_DISTANCE_ID, nothingCallback2);
  TheiaSerial::broadcastIds();

  for (int i = 0; i < MOTOR_COUNT; i++) {
    motors[i].attach(motorPins[i]);
    motors[i].writeMicroseconds(1500); // neutral position
  }

  analogReference(DEFAULT);
  pinMode(LIMIT_SWITCH_PIN, INPUT);
}

bool validateSpeed(float speed, int id) {
  // default is 0.5, which would mean its ok to move it since its in the middle
  float percentValue = 0.5;
  switch (id) {
    case 0:
      percentValue = excavatorPercent;
      if (isLimitSwitchTriggered && speed > 0) {
        return false;
      }
      break;
    case 1:
      percentValue = actuatorPercent;
      break;
  }
  bool movingBelowLimit = speed < 0 && percentValue < ACTUATOR_LIMIT_TOLERANCE;
  bool movingAboveLimit = speed > 0 && percentValue > (1.0 - ACTUATOR_LIMIT_TOLERANCE);
  return !movingAboveLimit && !movingBelowLimit;
}

void onExcavatorState(const ExcavatorState& data) {
  // process the incoming data
  float speeds[MOTOR_COUNT] = {
    data.excavatorLifterSpeed,
    data.conveyorSpeed,
    data.actuatorSpeed
  };
  for (int i = 0; i < MOTOR_COUNT; i++) {
    if (validateSpeed(speeds[i], i)) {
      // Map the speed to the pulse width
      int speedByte = (int)(((speeds[i] + 1.0) * 127.5));
      int pulseWidth = map(speedByte, 0, 255, REVERSE_PULSE_WIDTH, FORWARD_PULSE_WIDTH);
      motors[i].writeMicroseconds(pulseWidth);
    }
  }
}

void loop() {
  TheiaSerial::tick();

  // used to stop the excavator from hitting the robot when lifting it
  isLimitSwitchTriggered = (digitalRead(LIMIT_SWITCH_PIN) == HIGH);

  if (loopCount % 8 == 0) {
    // Read the potentiometer values
    float actuatorPotentiometer = analogRead(ACTUATOR_POTENTIOMETER_PIN);
    float excavatorPotentiometer = analogRead(EXCAVATOR_POTENTIOMETER_PIN);
    actuatorPercent = (float)map(actuatorPotentiometer, 0, 1023, 0, 100) / 100.0;
    excavatorPercent = (float)map(excavatorPotentiometer, 0, 1023, 0, 100) / 100.0;
    if (actuatorPercent == 0.0) actuatorPercent = 0.001;
    if (excavatorPercent == 0.0) excavatorPercent = 0.001;

    // Read the distance sensor value
    int distanceSensorValue = analogRead(DISTANCE_SENSOR_PIN);
    float distanceSensorVoltage = (distanceSensorValue / BOARD_MAX_ANALOG_VALUE) * MAX_VOLTS;
    // Calculate distance in cm using the formula from datasheet
    // https://global.sharp/products/device/lineup/data/pdf/datasheet/gp2y0a41sk_e.pdf
    float distance = 12.08 * pow(distanceSensorVoltage, -1.058);
    // Send the distance sensor data to the Raspberry Pi
    DistanceSensor distanceSensorData;
    distanceSensorData.distanceSensor = distance;
    TheiaSerial::sendFramedMessage(EXCAVATOR_DISTANCE_ID, distanceSensorData);

    // Create a LinearActuatorPercent struct to hold the percent values
    PotentiometerPercents excavatorPercents;
    excavatorPercents.excavatorLifterPercent = excavatorPercent;
    excavatorPercents.actuatorPercent = actuatorPercent;

    // Send the percent values to the Raspberry Pi
    TheiaSerial::sendFramedMessage(EXCAVATOR_PERCENT_ID, excavatorPercents);
  }

  delay(10);

  loopCount++;
}

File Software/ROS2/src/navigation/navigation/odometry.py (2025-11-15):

import asyncio
import rclpy
from rclpy.node import Node
from rclpy.action import ActionServer

from rclpy.callback_groups import ReentrantCallbackGroup, MutuallyExclusiveCallbackGroup


# the self driver agent action
from lunabotics_interfaces.msg import Point, Motors, Excavator, PathVisual, ExcavatorPotentiometer, AccelerometerCorrection, Config
from lunabotics_interfaces.action import SelfDriver
from lunabotics_interfaces.srv import TunePID
from navigation.pathfinding import distance
import rclpy.time
from sensors.spin_node_helper import spin_nodes

from navigation.pid import PIDController
from navigation.pid_tuner import tune_pid
from navigation.pid_tuner2 import PIDTuner


from std_msgs.msg import Float32
import math

MAX_ACTUATOR_PERCENT = 0.69
MIN_ACTUATOR_PERCENT = 0.2

# when the excavator lifter motor is at this %, the distance sensor can be used to detect the ground
DISTANCE_SENSOR_ENABLE_THRESHOLD = 0.7
# when the distance sensor is this far away, the excavator should stop and start digging
DISTANCE_SENSOR_TOLERANCE = 8  # cm

MAX_EXCAVATOR_LIFTER_PERCENT = 0.3
MIN_EXCAVATOR_LIFTER_PERCENT = 0.88

CONVEYOR_SPEED = 0.6

EXCAVATION_TIME = 10.0
BIN_TIME = 3.0

# seconds of time it waits to allow for positioning to update
PAUSE_TIME = 1.5

class Odometry(Node):
    """
        This node has an action server that takes requests to move the robot.
        It keeps track of the robot's position and orientation and wait until the robot reaches the requested position.
    """
    
    def __init__(self):
        super().__init__('odometry')

        # these make sure each subcriber/action/publisher gets time to run
        self.action_group = ReentrantCallbackGroup()      # For action server
        self.sensor_group = ReentrantCallbackGroup()      # For sensor callbacks
        self.control_group = MutuallyExclusiveCallbackGroup()  # For control outputs
        self.config_group = ReentrantCallbackGroup()      # For configuration

        # action server is used to drive the robot
        # it's in its own callback group so it can run async functions
        self._action_server = ActionServer(
            self,
            SelfDriver,
            'self_driver',
            execute_callback=self.on_goal_request,
            cancel_callback=self.on_cancel,
            callback_group=self.action_group
        )
        
        # action values to store for when its done
        self.goal_handle = None
        self.was_cancelled = False
        self.start_time = self.get_clock().now()
        self.prev_time = self.start_time
        self.total_pause_time = 0.0

        # margin of error for rotation (degrees)
        self.deg_tolerance = 7.0 
        # margin of error for movement (centimeters)
        self.dist_tolerance = 25.0
        # margin of error for excavator actuators (percent)
        self.actuator_tolerance_percent = 0.03

        # initalize position
        self.position = Point()
        self.position.x = 448.0
        self.position.y = 100.0

        # initalize orientation
        self.orientation = 0.0
        self.last_orientation_time = self.get_clock().now()
        self.has_corrected_orientation = False
        
        # initalize linear actuator percentage for opening the bin
        # 0% is contracted and 100% is extended
        self.actuator_percent = 0.0
        self.excavator_lifter_percent = 0.0
        self.excavator_ground_distance = -1.0  # cm
        
        # ros publishers and subscribers
        # control
        self.motor_pub = self.create_publisher(Motors, 'physical_robot/motors', 10, callback_group=self.control_group)
        self.excavate_pub = self.create_publisher(Excavator, 'physical_robot/excavator', 10, callback_group=self.control_group)
        self.orientation_corrector = self.create_publisher(AccelerometerCorrection, 'sensors/accelerometer_correction', 10, callback_group=self.control_group)
        
        # config
        self.config_sub = self.create_subscription(Config, 'website/config', self.on_config, 10, callback_group=self.config_group)
        self.website_path_visualizer = self.create_publisher(PathVisual, 'navigation/odometry_path', 10, callback_group=self.config_group)
        self.pid_tuner_server = self.create_service(TunePID, 'pid_tuner', self.on_pid_tune, callback_group=self.config_group)
        
        # sensors
        self.position_sub = self.create_subscription(Point, 'sensors/position', self.on_position, 10, callback_group=self.sensor_group)
        self.orientation_sub = self.create_subscription(Float32, 'sensors/orientation', self.on_orientation, 10, callback_group=self.sensor_group)
        self.excavator_distance_sub = self.create_subscription(Float32, 'sensors/excavator_distance', self.on_excavator_distance, 10, callback_group=self.sensor_group)
        self.excavator_percent_sub = self.create_subscription(ExcavatorPotentiometer, 'sensors/excavator_percent', self.on_excavator_percent, 10, callback_group=self.sensor_group)
        
        # PID controllers (some notes from ChatGPT: )
        # Kp: Proportional Gain
            #  Corrects based on the current error.
            #  High Kp = fast response, but may overshoot or oscillate.
            #  Low Kp = slower reaction, smoother approach.
        # Ki: Integral Gain
            # Corrects based on the sum of past errors (helps eliminate bias/drift).
            # High Ki = aggressive accumulation (can cause instability).
            # Low/0 Ki = ignores long-term drift (safer for short-term motion like rotation).
        # Kd: Derivative Gain
            # Corrects based on the rate of change of error (slows down before overshooting).
            # High Kd = dampens oscillations, slows final approach.
            # Too much = system becomes unresponsive.
        self.orientation_pid = PIDController(Kp=0.011, Ki=0.0005, Kd=0.001, output_limits=(-0.5, 0.5))
        self.linear_drive_pid = PIDController(Kp=0.013, Ki=0.001, Kd=0.01, output_limits=(-0.55, 0.55))
        # for some reason this one starts doing big loops around the target when you give it some Ki and Kd on the simulation
        # especially when the speed of the simulation is increased
        self.angular_drive_pid = PIDController(Kp=0.004, Ki=0.0, Kd=0.0001, output_limits=(-0.19, 0.19))
        
        self.bin_actuator_pid = PIDController(Kp=0.6, Ki=0.0, Kd=0.001, output_limits=(-0.5, 0.5))
        self.excavator_lifter_pid = PIDController(Kp=0.6, Ki=0.0, Kd=0.001, output_limits=(-0.5, 0.5))
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

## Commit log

2024-11-07 Made some Swerve
    [211-0000 (Master Sketch).SLDPRT, 211-0001 (6mm ID Flanged Bearing).STEP, 211-0010 (Carbon-Fiber Tube).SLDPRT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]
2024-11-15 Made a lot of changes to CAD & Added Software file
    [211-0000 (Master Sketch).SLDPRT, 211-0010 (Carbon-Fiber Tube).SLDPRT, 211-0014 (6mm D-Shaft).SLDPRT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]
2025-01-22 Version when parts were purchased
    [211-0000 (Master Sketch).SLDPRT, 211-0002 (Master Sketch v2).SLDPRT, 211-0010 (Belt Protection Panel).SLDPRT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]
2025-01-22 Adding untracked files
    [211-0003 (Master Sketch v3).SLDPRT, 211-0004 (Wheel Mount Assembly).SLDASM, 211-0010 (Belt Protection Panel).SLDPRT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]
2025-01-24 Files for Mock-Up for Swerve Drive
    [211-0003 (Master Sketch v3).SLDPRT, 211-0021 (Gearbox Casing).SLDPRT, 211-0021 (Gearbox Casing).STL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]
2025-01-26 Killed Part numbering system
    [211-0000 (Master Sketch).SLDPRT, 211-0001 (6mm ID Flanged Bearing).STEP, 211-0001 (Virtual Swerve).SLDPRT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]
2025-02-07 Switched to correct directory for nextjs.yml
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2025-02-07 kicad powerboard
    moved to lunabotics github
    [Electrical schematic-B_Cu.gbr, Electrical schematic-B_Mask.gbr, Electrical schematic-B_Paste.gbr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]
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2025-02-07 Fixed Project
    [PWMEncoder.kicad_pcb, PWMEncoder.kicad_sch]
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2025-02-10 Github actions doesn't like "SOCKET" in routes without the prepare script
2025-02-10 Fixed web sockets!!
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2025-02-20 Moved swerve to its own folder
    [12mm Coupler.STEP, 12mm Tube 40mm length.SLDPRT, 28 Tooth Bevel Gear.STEP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]
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2025-02-22 rewiring to be smaller/new mux/ fixing xt60
    [Electrical schematic.kicad_pcb, Electrical schematic.kicad_sch, voltage_reading.kicad_sch]
2025-02-22 Started PWM Encoder PCB
    [PWMEncoder.kicad_pcb, PWMEncoder.kicad_sch]
2025-02-22 Edited silkscreen labels, moved USB port to edge
    [Electrical schematic.kicad_pcb]
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2025-02-23 finishing pcb
    adding mounting holes and different resistor for buck converter to convert to 5.15V.
    [Electrical schematic.kicad_pcb, buckconverter.kicad_sch]
2025-02-23 adding horizontal surface mount usba
    [Electrical schematic.kicad_pcb, Electrical schematic.kicad_sch]
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2025-02-23 idk i did something
    [Electrical schematic-B_Cu.gbr, Electrical schematic-B_Mask.gbr, Electrical schematic-B_Paste.gbr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]
2025-02-24 Added Dylan's wheel and also other things apparently
    [Blocking.SLDPRT, Differential Gearbox Case.SLDASM, Female Steel Ball Linkage.SLDASM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]
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2025-02-26 Add files via upload
    New Chassis made of 1x1", 1/16" bars and gussets.
    [Chassis_2_Assy.SLDASM]
2025-02-27 created an entire board in 3 minutes
    worked with my electrical lead quinn
    [XT60ConnectorBoard.kicad_pcb, XT60ConnectorBoard.kicad_sch]
2025-02-27 2x1 shaft sketches
    Added 2x1 shaft sketches and spacers and added left and right excavator side sketches
    [Excavator Mastersketch.SLDPRT]
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2025-03-12 Excavator Mastersketch
    new gussets
    [Excavator Mastersketch.SLDPRT]
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2025-03-17 drawing ready to cut
    [Waterjet Reference.SLDDRW]
2025-03-18 The blocking was outdated. Whoops.
    [Blocking.SLDPRT, Excavator Mastersketch.SLDPRT, Heel Gusset.SLDPRT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]
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2025-03-19 Starting building Excavator Assembly from Mastersketch
    [8982K402_Multipurpose 6061 Aluminum 90 Degree Angle.SLDPRT, Blockingv2.SLDPRT, Bottom Interface Plate.STEP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]
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2025-03-21 final scoop 5 in
    [Lunabotics Scoop.SLDPRT]
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2025-03-25 Fixed issue with partial lidar data showing up on website
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2025-03-28 3/27 Push from Dylan Kim
    3/27 Push from Dylan Kim
    [RBP_Case.SLDPRT, RBP_Case.STL, Rocker Master Sketch.SLDPRT]
2025-03-28 3rd Iteration PCB
    New PCB
    [Electrical schematic.kicad_pcb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]
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2025-03-31 new 2.22 excavator spacer
    [Excavator Spacer 2.22 in.SLDPRT, Excavator Spacer 2.22 in.STL]
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2025-04-06 Moved arduino files into thier own folders so they can be uploaded, and solved serial issue
    [Motors.ino, UWBAnchor.ino, UWBTag.ino]
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2025-04-12 Prevented deadlock in the planner by using multi threaded executor
2025-04-12 Fixed a few bugs in odometry
    [odometry.py]
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2025-04-16 Adding lots of stuff
    [12mm Tube 40mm length.SLDPRT, 8982K402_Multipurpose 6061 Aluminum 90 Degree Angle.DWG, 8982K402_Multipurpose 6061 Aluminum 90 Degree Angle.STEP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]
2025-04-17 Fixed distance parsing bug with uwb modules
    [UWBAnchor.ino, UWBTag.ino]
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2025-04-18 Add 2 new ekf files
    These aren't tested. Option 1 is supposed to take the linear x and y as control inputs in the prediction phase (I think it assumes they are low noise measurements) to directly predict the next velocity and position. Option 2 treats the acceleration data as noisy measurements similar to the distances measured by the 3 beacons.
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2025-04-19 Added power data board, fixed bugs with beacon code
    [PowerData.ino, UWBAnchor.ino, UWBTag.ino]
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2025-04-20 Worked on odometry, fixed mock positioner being flipped
    [mock_positioning.py, odometry.py]
2025-04-20 Improved the stop predicate algorithm, but lots more needs to be done because sometimes it doesn't stop turning at the right time
    [odometry.py]
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2025-04-22 Buck Board Version 1
    Added capacitor for Pi rail
    [Electrical schematic.kicad_pcb, Electrical schematic.kicad_sch, buckconverter.kicad_sch]
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2025-04-23 Got power data to correctly output current by dividing by 16 and switching pins around
    [PowerData.ino]
2025-04-30 Worked on simulation and got the robot moving around correctly (sometimes)
    [mock_positioning.py, odometry.py]
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2025-05-07 PowerBoard 2 first iteration
    [PowerBoard2.kicad_pcb, PowerBoard2.kicad_sch]
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2025-05-07 Updated Schematic, Rerouted Some Things
    [PowerBoard2.kicad_pcb, PowerBoard2.kicad_sch]
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2025-05-07 widened traces for 5V output
    [PowerBoard2.kicad_pcb, PowerBoard2.kicad_sch]
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2025-05-09 Updated Board to use two INA226
    [PowerBoard2.kicad_pcb, PowerBoard2.kicad_sch]
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2025-05-10 Added motors arduino code and fixed theiaserial
    [Motors.ino, odometry.py]
2025-05-11 Fixed bug with uwb tag by converting to degrees
    [UWBTag.ino, arduino_uploader.py]
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2025-05-12 Created a CAD for the chassis
    [1602-0032-0008 assembly.STEP, 4BarHolder.STL, 8982K402_Multipurpose 6061 Aluminum 90 Degree Angle.SLDPRT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]
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2025-05-13 added reverse functionality for goal of odometry action server
    [odometry.py]
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2025-05-14 Added 3d robot rendering (new 3d model coming soon)
    [lunabot.blend, lunabot.obj]
2025-05-14 Added ability for website to reset the simulation
    [mock_positioning.py, odometry.py]
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2025-05-15 Added orientation correction to find initial rotation
    [mock_positioning.py, odometry.py]
2025-05-15 Removed some debug messages and got orientation correction simulation working
    [mock_positioning.py, odometry.py]
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2025-05-16 Potentially fixed delays on waiting for new messages to come into theia serial
    [PowerData.ino]
2025-05-16 Added config and serial port visualizer
    [lunabot.obj]
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2025-05-16 finally fixed the lag on odometry by putting subscribers in different threads!
    [mock_positioning.py, odometry.py]
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2025-05-20 Updated ThreeJS rendering of robot.
    [lunabot4.blend, lunabot4.obj, lunabot_base.obj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]
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2025-05-20 Added excavator positioning to the robot context
    [lunabot4.blend, lunabot4_excavator.obj, lunabot_base.obj]
2025-05-20 Fixed a couple of issues with config
2025-05-21 Added lidar rendering to ThreeJS dashboard section
    [lunabot_excavator.obj]
2025-05-21 worked on new pid tuner, fixed some website layout issues, added excavator limiting
    [Excavator.ino, UWBTag.ino, mock_positioning.py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]
2025-05-21 Attempted to fix issues with auto tune
    [odometry.py]
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2025-05-21 Corrected lidar rendering in ThreeJS canvas.
2025-05-21 Fixed Filled Zones on PCB
    [PowerBoard2.kicad_pcb]
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2025-05-21 Got tuner working and solved a few issues with new messages system on website
    [mock_positioning.py, odometry.py]
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2025-05-22 Fixed robot view in 3d
    [odometry.py]
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2025-05-22 Fixed obstacle scaling issue and various website bugs
    [odometry.py]
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2025-05-22 Made basic CAD for rockers
    [6mm ID 12mm OD bearing.STEP, Blocking.SLDPRT, Motor.SLDPRT]
2025-05-22 Moving Files from Chassis v4 to DriverBase
    Moving Files from Chassis v4 to DriverBase
    [Bearing Holder Standard.SLDPRT]
2025-05-22 moving files around
    moved bearing holder mirrored
    [Bearing Holder Mirrored.SLDPRT, Bearing Holder Standard.SLDPRT]
2025-05-22 Updated the robot rendering to move terrain based on robot position and corrected lidar positioning.
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2025-05-28 reverted some changes from comp so that sim can be shown
    [mock_positioning.py, odometry.py]
